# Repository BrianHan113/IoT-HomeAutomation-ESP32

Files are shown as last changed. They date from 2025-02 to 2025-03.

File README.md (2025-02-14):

# IoT-HomeAutomation-ESP32

IoT Home Automation system using ESP32s to control various peripherals, developed with amazing help and under supervision of Alex Risos from Risos Enterprises for my summer 2024-25 internship. This project comes with pre-made examples of peripherals, but the esp32-Receiver-Firmware can be flashed and easily modified on any ESP32 for any custom functionality. There are 2 versions of the project, read the Known Issues section to see why.

<table align="center">
  <tr>
    <th style="text-align:center;">Simplified (Recommended)</th>
    <th style="text-align:center;">Full</th>
  </tr>
  <tr>
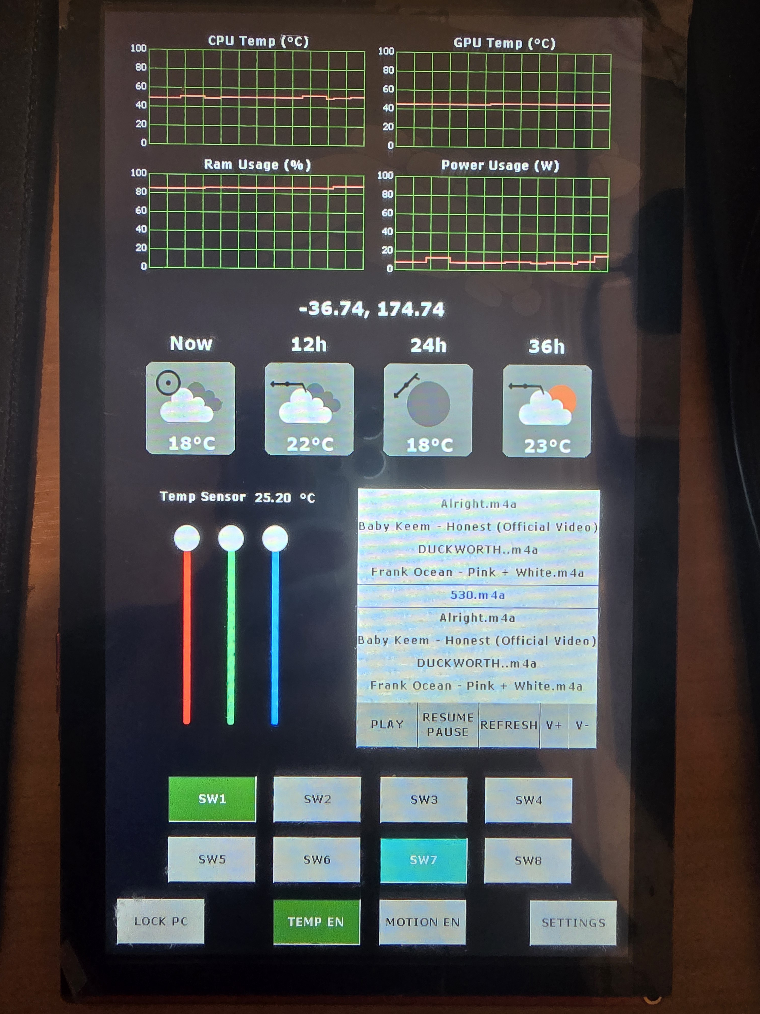
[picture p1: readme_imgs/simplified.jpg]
    <td align="center"></td>
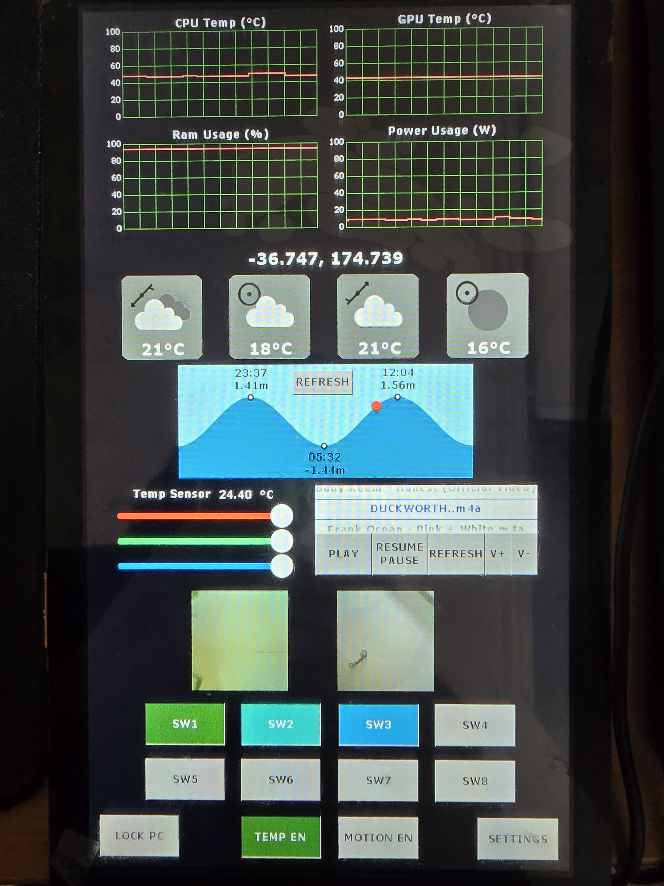
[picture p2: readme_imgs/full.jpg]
    <td align="center"></td>
  </tr>
</table>

## Demo Video (Simplified Version)

<a href="https://www.youtube.com/watch?v=xSinmTBI6Ek" target="_blank" rel="noopener noreferrer">
    
</a>

This demo covers the linking and usage of the esp32-SSR, esp32-Status-LED, esp32-Motion-Sensor, and esp32-Temp-Sensor. I linked them all onto one switch for demonstration purposes, but you could obviously link them to other switches. The SSR isn't hooked up to anything, but it is rated for any 100-240VAC load. With just this bare bones setup, you could automate many things, like setting off an emergency alarm when the temperature sensor triggers, turning on a light bulb when entering a room, etc. 

## Summary of features
* Detection and pairing with powered ESPs that have the receiver firmware programmed
* Link any paired ESP to any of 8 switches on nextion display, can link multiple ESPs on one switch
* Control of 2-channel low-level solid state relays
* Quadruple state switches with actions of A, B, A+B or OFF
* Control of LED strips (Status-LED which shows a colour dependant on Gpu Temperature, and LED-Strip for colour picking using RGB sliders on nextion GUI)
* Trigger switches using a Motion Sensor
* Trigger switches using a Temperature Sensor
* Trigger switches and/or enable sensors with a scheduler
* 2 Camera slots for image captures (Not in simplified version)
* Weather information with adjustable time range
* Tide extremes and current tide height information (Not in simplified version)
* CPU Temperature, GPU Temperature, Ram Usage and Power consumption shown on nextion display as waveforms
* Music player
* Lock PC button

## How to Use
### Getting started
1. Flash esp32-HW-monitor on central esp32-s3
2. Flash as many receiver esps as you would like
3. Connect COM port of esp32-s3 to a USB port on your computer (See wiring diagram)
4. Flash whichever .HMI file (simplified or full) in nextion-HMI onto the nextion 
5. Make sure the esp32-s3 and the nextion share a common ground
6. Start the ArduinoWeatherHardwareMonitor desktop app, make sure to run as admin. For quick setup with no TideAPI functionality, execute ArduinoWeatherHardwaremonitor_RELEASE/SerialSender.exe. If you want Tide functionality, you must add your API key to the Secret_PLACEHOLDER.cs file, and recompile the project in Visual Studio.
7. Select the appropriate serial port by right clicking the tray icon

At this point, the waveforms and weather information should have loaded on the main page, the LOCKPC button and the music player should be working. Right click the tray icon to select your WinAmp installation folder and your music folder. You will only have to do this once, unless you change your WinAmp path or your music folder. The music player plays MP3, MIDI, MOD, MPEG-1, AAC, M4A, FLAC, WAV, WMA, Ogg Vorbis.

### General Information
I have included all the specific hardware/sensors/parts I used for all the different peripherals under Wiring Diagrams. You can definitely use different hardware, but you will likely have to modify some code in the peripheral projects.

All peripheral projects have EspIDs in their main.cpp files. You can change the names of these to anything you want. E.g. "living room lights", "garage motion sensor", etc.

In settings, you can click directly on any numbers to bring up a on-screen numerical keyboard, and press the <strong>X</strong> to clear selections. You should always hit <strong>APPLY</strong> after changing any settings to keep the system up to date and accurate to what is shown on the settings page.

### Linking and Turning Peripherals on/off

Can be used for esp32 or esp8266, just flash the appropriate receiver firmware.

<table align="center">
  <tr>
    <td><div>
    <ol>
      <li>Press <strong>SETTINGS</strong>, then <strong>SCANESPS</strong> in the top left. Wait a couple of seconds for the peripherals to connect.</li>
      <li>Link a switch to any peripheral and hit <strong>APPLY</strong> on the bottom left.</li>
      <li>Exit back to the main page. You should now be able to turn that peripheral on/off using the switch you selected.</li>
    </ol>
    <p>Each switch has 4 states which go in sequence of ONA, ONAB, ONB, OFF. This allows each peripheral to handle 2 different actions, A and B, where ONAB is turning on both at the same time. This synergizes with usage of 2 channel SSRs, as seen in esp32-SSR. </p> <p>For the standard esp32/esp8266-Receiver-Firmware, all three ON states will just turn the builtin LED on, but this can be easily modified.</p>
  </div></td>
    <td align="center"><div style="align-items: center;">
  <div>
    <div>
      <h4>Linking Switches</h4>
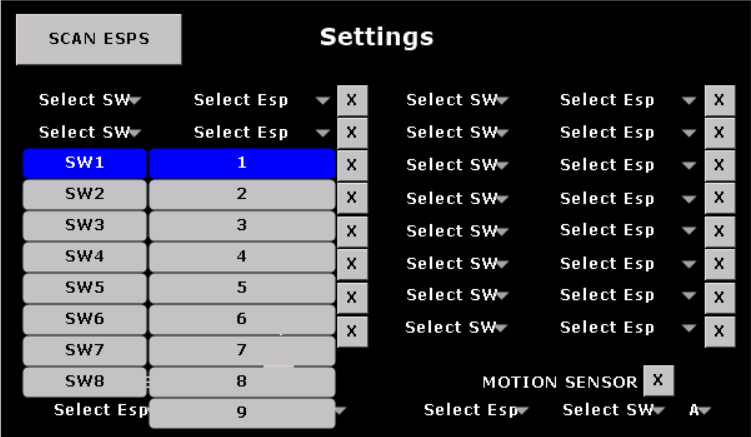
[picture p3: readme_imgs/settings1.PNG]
      
    </div>
    <div>
      <h4>4 Switch States in order</h4>
      
    </div>
  </div>
</div></td>
  </tr>
</table>

### Solid State Relays
Link to a switch in settings, and press the switch on the main screen to turn on whatever channel(s) you want. 

### Temperature Sensor

<table align="center">
  <tr>
    <td><div>
    <ol>
      <li><strong>Select ESP</strong>: The device that is connected to the temperature sensor</li>
      <li><strong>Select SW</strong>: The Switch that should be triggered when the temperature exceeds the trigger temperature</li>
      <li><strong>Channel selection</strong>: Which channel of the switch should be turned on (A, B, AB)</li>
      <li><strong>Trigger SW at</strong>: The temperature threshold, in celcius, where anything that exceeds it will trigger the connected switch</li>
      <li><strong>Hysterisis</strong>: What percentage of the trigger temperature does the measured temperature need to fall below in order to turn the switch off. E.g., if trigger temp is 50C, and hystersis is 50%, when triggered, the measured temperature must fall below 25C in order for the switch to turn off automatically.</li>
    </ol>
    <p>After selecting these settings, you must hit <strong>APPLY</strong> and navigate back to the main screen, and press <strong>TEMP EN</strong> to enable the sensor to make automatic changes. If it any point you wish to override the sensor/ignore it, just press <strong>TEMP EN</strong> again to disable it.</p>
  </div></td>
    <td align="center"><div style="align-items: center;">
  <div>
    <div>
      <h4>Temperature Sensor</h4>
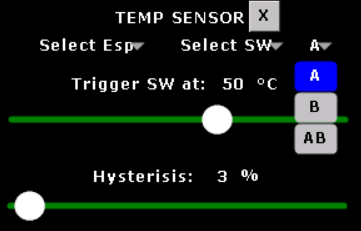
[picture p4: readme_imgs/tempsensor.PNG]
      
    </div>
  </div>
</div></td>
  </tr>
</table>

### Motion Sensor

<table align="center">
  <tr>
    <td><div>
    <ol>
      <li><strong>Select ESP</strong>: The device that is connected to the motion sensor</li>
      <li><strong>Select SW</strong>: The Switch that should be triggered when motion is detected</li>
      <li><strong>Channel selection</strong>: Which channel of the switch should be turned on (A, B, AB)</li>
      <li><strong>Timeout</strong>: How long the switch stays on after motion is detected, before turning off. 0 minutes will default to 1 second.</li>
    </ol>
    <p>After selecting these settings, you must hit <strong>APPLY</strong> and navigate back to the main screen, and press <strong>MOTION EN</strong> to enable the sensor to make automatic changes. If it any point you wish to override the sensor/ignore it, just press <strong>MOTION EN</strong> again to disable it.</p>
  </div></td>
    <td align="center"><div style="align-items: center;">
  <div>
    <div>
      <h4>Motion Sensor</h4>
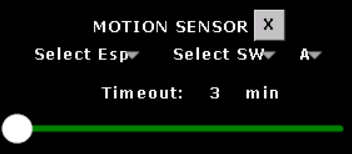
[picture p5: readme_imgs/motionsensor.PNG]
      
    </div>
  </div>
</div></td>
  </tr>
</table>

### Scheduler
Make sure the desktop app is open, and the serial port to the central esp is connected.

<table align="center">
  <tr>
    <td><div>
    <ol>
      <li><strong>Select SW</strong>: The Switch that should be turned on at Start time, and off at End time</li>
      <li><strong>Channel selection</strong>: Which channel of the switch should be turned on/off (A, B, AB)</li>
      <li><strong>Start</strong>: Turn selected switch on at this time</li>
      <li><strong>End</strong>: Turn selected switch off at this time</li>
      <li><strong>X</strong>: Will unschedule the switch</li>
    </ol>
    <p>For the temperature and motion sensors, the scheduler will turn the <strong>TEMP EN</strong> and <strong>MOTION EN</strong> on/off instead. For this case, the channel selection is not needed, and hence is ignored.</p>
  </div></td>
    <td align="center"><div style="align-items: center;">
  <div>
    <div>
      <h4>Scheduler</h4>
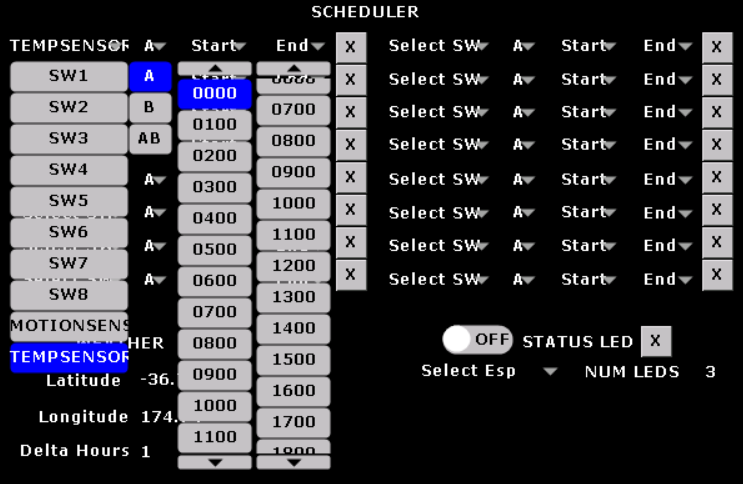
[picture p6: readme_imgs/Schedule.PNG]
      
    </div>
  </div>
</div></td>
  </tr>
</table>

### LED Strip

<table align="center">
  <tr>
    <td><div>
    <ol>
      <li><strong>Select ESP</strong>: The device that is connected to the LED Strip</li>
      <li><strong>NUM LEDS</strong>: How many LEDs to show.</li>
      <li><strong>Link</strong>: You must then link the LED Strip device to a switch in order to turn it on.</li>
      <li><strong>Colour</strong>: Change the colour of the LED Strip using the 3 RGB sliders on the main screen.</li>
    </ol>
  </div></td>
    <td align="center"><div style="align-items: center;">
  <div>
    <div>
      <h4>LED Strip</h4>
      
    </div>
    <div>
      <h4>Link LED Strip</h4>
      
    </div>
  </div>
</div></td>
  </tr>
</table>

### Status LED Strip

<table align="center">
  <tr>
    <td><div>
    <ol>
      <li><strong>Select ESP</strong>: The device that is connected to the LED Strip</li>
      <li><strong>NUM LEDS</strong>: How many LEDs to show.</li>
      <li><strong>Turn On</strong>: Apply the settings first, then turn the strip on and off using the switch.</li>
      <li><strong>Brightness</strong>: Use the slider to change the brightness of the LED strip.</li>
    </ol>
    <p>Currently, the status LED strip just reports the GPU temperature scaled from 30 to 100 degrees celcius to the CHSV colour scale, where 100C is red, and 30C is aqua, with everything else in between. You can modify this in the sendTempData task in HW-monitor, and the receiver_espnow in Status-LED to add whatever else you want it to report.</p>
    <p>Also note that the ON/OFF switch and the brightness slider do not require hitting <strong>APPLY</strong> to take action.</p>
  </div></td>
    <td align="center"><div style="align-items: center;">
  <div>
    <div>
      <h4>Status LED Strip</h4>
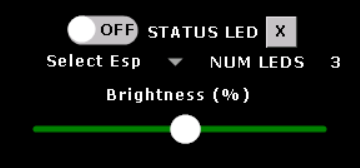
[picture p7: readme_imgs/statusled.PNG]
      
    </div>
</div></td>
  </tr>
</table>

### Weather Settings
<table align="center">
  <tr>
    <td><div>
    <ol>
      <li><strong>Lat & Long</strong>: Standard Lat Long, + for North of equator, + for East of Prime Meridian</li>
      <li><strong>Delta Hours</strong>: Time gap between each weather forecast. E.g. delta hour of 6 will give a forecast of now, +6h, +12h, +18h in the main screen.</li>
      <li>Hit <strong>APPLY</strong>, It will take a couple seconds for the weather icons to be updated.</li> 
    </ol>
    <p>Note that the weather is automatically updated every 5 minutes. Pressing <strong>APPLY</strong> manually fetches new data.</p>
  </div></td>
    <td align="center"><div style="align-items: center;">
  <div>
    <div>
      <h4>Weather Settings</h4>
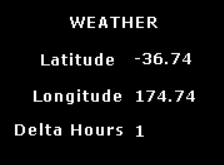
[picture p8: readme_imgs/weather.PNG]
      
    </div>
  </div>
</div></td>
  </tr>
</table>

## Wiring Diagrams

### Nextion and Central ESP
* Nextion - NX1060P101-011C-I, RX of Nextion to pin 17, TX of Nextion to pin 18
* ESP32-S3 - Connect USB Port on the ESP to the PC
* SD Card in Nextion if using ESP-CAMs, otherwise not necessary
* Make sure ESP shares common ground with Nextion and the PSU
<div>
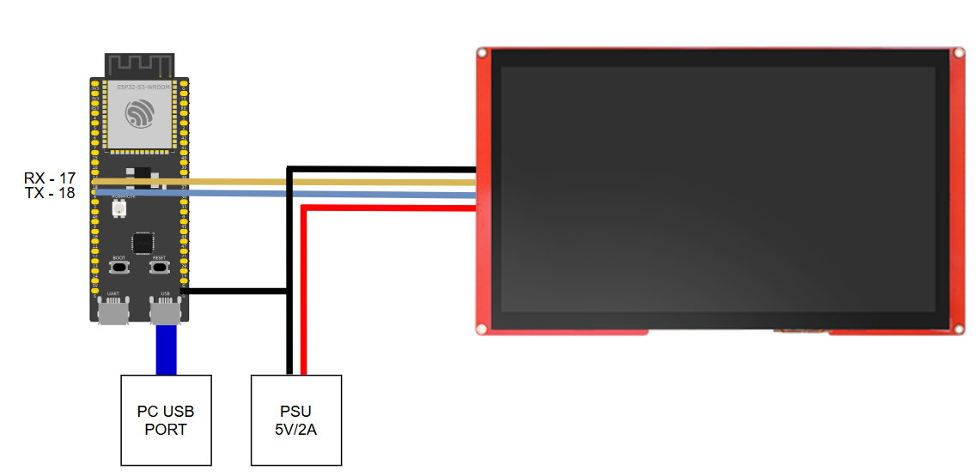
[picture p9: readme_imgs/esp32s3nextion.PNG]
  
</div>

### Temperature Sensor
* ESP32 - data line from sensor connected to GPIO pin 26.
* DHT22 - 3.3V VCC
* 1 KOhm Resistor - Make sure to add a pull-up resistor between data and VCC for stable transmission (see official DHT22 documentation).
<div>
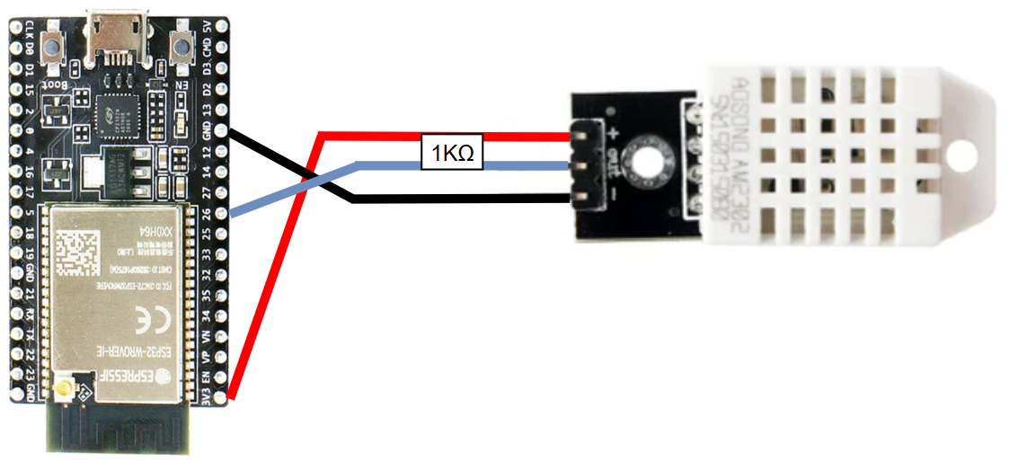
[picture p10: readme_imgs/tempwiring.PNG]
  
</div>

### Motion Sensor
* ESP32 - Data line on PIR sensor to pin 13
* PIR Sensor - HC-SR501, 5V VCC
<div>
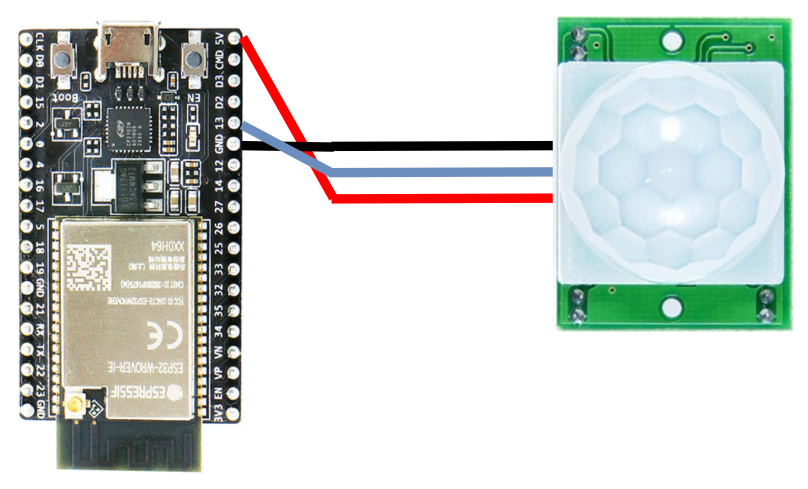
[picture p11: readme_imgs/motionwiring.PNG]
  
</div>

### LED Strip & Status LED Strip
* ESP32 - Primary data line of LED Strip connected to pin 26
* LED Strip - WS2815 12V LED Strip 
* I have 19 LEDs on my LED strip, but you should change that definition to however many LEDs you have in the main file of the esp32-LED-strip project.
<div>
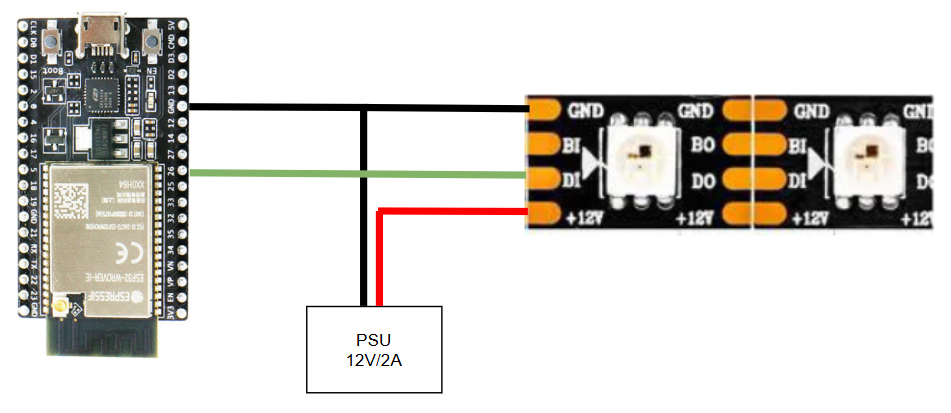
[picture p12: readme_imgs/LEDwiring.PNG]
  
</div>

### Solid State Relays
* ESP32
* SSR - G3MB-202P 2-channel low-level, 5V DC input, 240VAC 2A output
* Channels 1 and 2 are controlled by esp32 pins 27 and 26 respectively. 
<div>
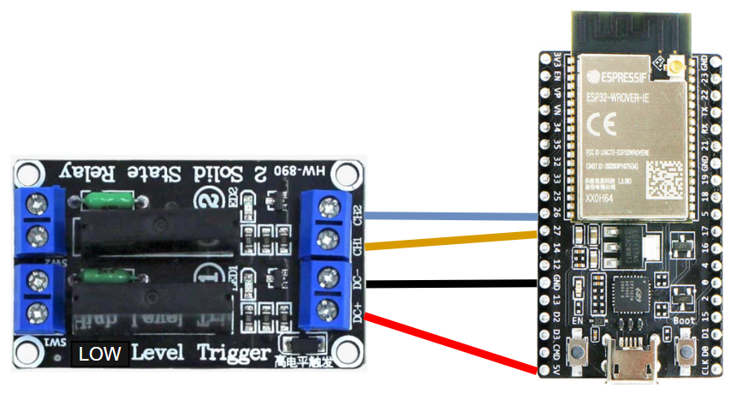
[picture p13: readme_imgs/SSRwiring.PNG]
  
</div>

## Known Issues
* Camera capture is very slow, around 10-15 seconds just for a single still image, and during this all buttons are unresponsive. It "works", but is generally pretty unusable, and hence has been disabled. It can easily be enabled by uncommenting code in the setup() function in the main file of HW-Monitor and filling in secret files in the HW-Monitor and CAM projects for WiFi SSID and Password.
* Tide data is also excluded in the simplified version, as the API used for the data (Stormglass.io) is unstable and could likely get rid of their free tier pricing. If stormglass is still free when reading this, or you have a paid api key, you can simply uncomment the task in the setup() function in the main file of HW-Monitor where the tasks are created, and provide your api key in the secret file in the ArduinoHardwareWeatherMonitor C# app.
* Make sure to select the serial port in the desktop app first, and then configure any settings with the receiver ESPs. Doing it the other way causes problems with the central ESP's memory and will result in unstable behaviour.

## Thank You
Alex Risos for supervising this project and always providing amazing guidance, help, and feedback. Definitely would not have been able to complete this project without his help.

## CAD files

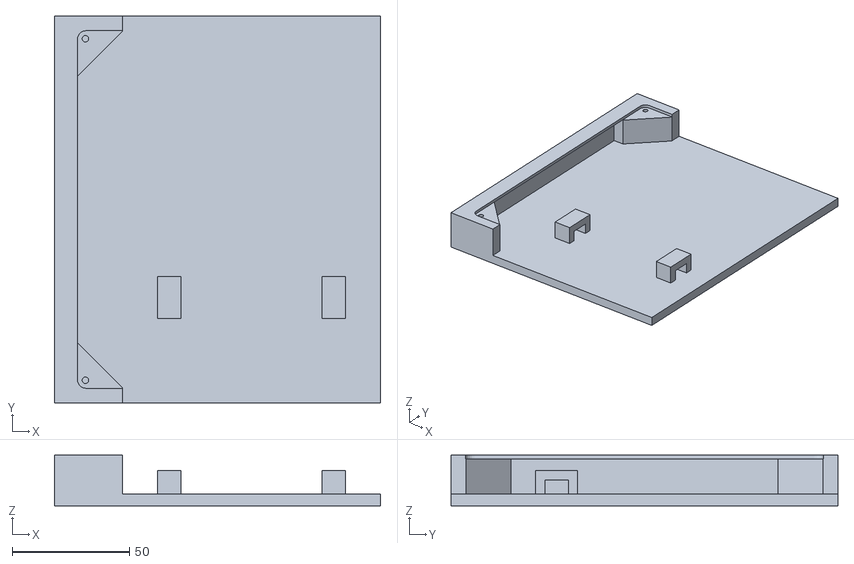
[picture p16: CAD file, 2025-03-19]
CAD-assets/nextion_mount_simplehalf.stl
139.0 x 165.0 x 21.6

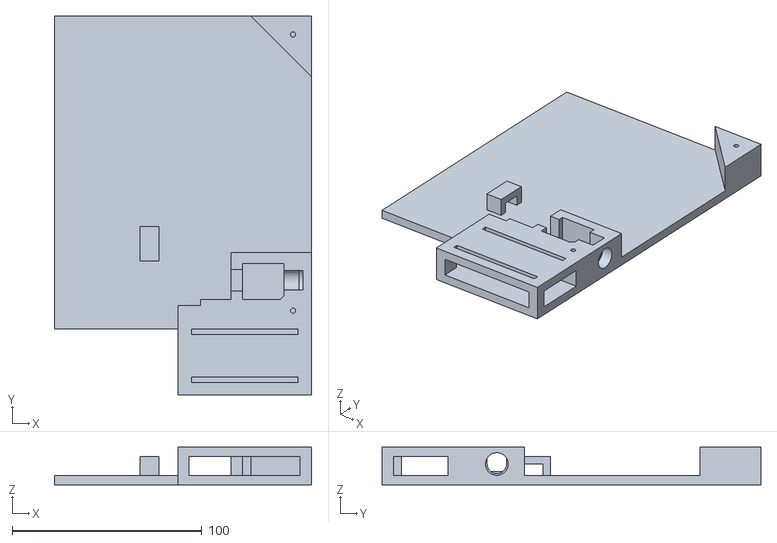
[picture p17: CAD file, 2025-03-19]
CAD-assets/nextion_mount_compelxhalf.stl
135.5 x 199.7 x 20.0

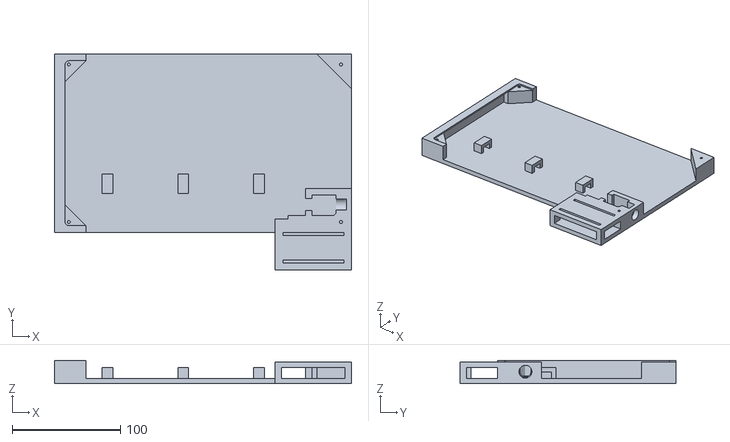
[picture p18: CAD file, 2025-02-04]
CAD-assets/Body4.stl
274.5 x 199.7 x 21.6

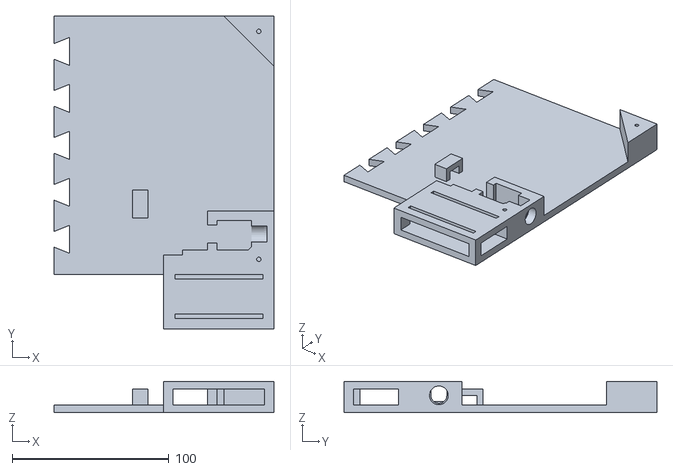
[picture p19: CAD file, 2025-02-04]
CAD-assets/espHalf.stl
140.5 x 199.7 x 20.0

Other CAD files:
CAD-assets/waireHalf.stl
CAD-assets/camera-case.f3z

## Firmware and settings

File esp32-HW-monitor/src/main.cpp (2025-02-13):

// Copyright (c) 2025 RisosEnterprises Ltd. All rights reserved.
// Developed by RisosEnterprises Ltd, Auckland, New Zealand.
// Licensed under Creative Commons Attribution-NonCommercial 4.0 International (CC BY-NC 4.0).
// See https://creativecommons.org/licenses/by-nc/4.0/ for details.
// Author: Brian Han

// USING ESP32-S3 with COM and USB port
// Because we set ARDUINO_USB_CDC_ON_BOOT=1 in setup,
// Serial0 is our extra Serial, and Serial is our normal Serial
// Serial0 -> COM Port
// Serial  -> USB Port
// Usage: Send & receive data at COM port, use USB port as normal for debugging

#include "tasks.h"
#include "espnow_manager.h"
#include "secrets.h"
#include "WiFi.h"
#include "addresses_helper.h"
#include "esp_wifi.h"
#include "security_camera.h"

HardwareSerial nextion(2);

SemaphoreHandle_t hardwareDataSemaphore;
SemaphoreHandle_t weatherBinSemaphore;
SemaphoreHandle_t tideBinSemaphore;
QueueHandle_t commandQueue;
QueueHandle_t sendNextionQueue;
const uint8_t COMMAND_QUEUE_LEN = 10;
const uint8_t SEND_NEXTION_QUEUE_LEN = 50;

// All task handles
TaskHandle_t receiveHardwareDataHandle = NULL;
TaskHandle_t sendNextionSerialHandle = NULL;
TaskHandle_t sendHardwareDataHandle = NULL;
TaskHandle_t sendWeatherDataHandle = NULL;
TaskHandle_t sendTideDataHandle = NULL;
TaskHandle_t receiveNextionSerialHandle = NULL;
TaskHandle_t executeCommandsHandle = NULL;
TaskHandle_t sendTempDataHandle = NULL;

void setup()
{
  Serial0.begin(115200);
  Serial.begin(115200);
  nextion.begin(115200, SERIAL_8N1, 18, 17); // RX, TX

  delay(3000);

  WiFi.mode(WIFI_STA);
  WiFi.disconnect();
  esp_wifi_set_channel(1, WIFI_SECOND_CHAN_NONE);

  // Setup for camera capture functionality - see README
  // WiFi.mode(WIFI_AP_STA);
  // WiFi.begin(WIFI_SSID, WIFI_PASS);

  // // Wait for WiFi connection
  // int tries = 0;
  // while (WiFi.status() != WL_CONNECTED && tries < 10)
  // {
  //   delay(500);
  //   Serial.println("Connecting to WiFi...");
  //   tries++;
  // }

  // if (!SPIFFS.begin(true))
  // {
  //   Serial.println("SPIFFS initialization failed!");
  //   return;
  // }

  if (esp_now_init() != ESP_OK)
  {
    Serial.println("ESP-NOW init failed");
    return;
  }
  Serial.println("Initialized ESP-NOW");

  esp_now_register_recv_cb(OnDataRecv);
  espNowAddReceiver(broadcastAddress);

  hardwareDataSemaphore = xSemaphoreCreateCounting(2, 0); // 2 slots for sendHardwareData and sendTempData
  weatherBinSemaphore = xSemaphoreCreateBinary();
  tideBinSemaphore = xSemaphoreCreateBinary();
  commandQueue = xQueueCreate(COMMAND_QUEUE_LEN, sizeof(char[500]));
  sendNextionQueue = xQueueCreate(SEND_NEXTION_QUEUE_LEN, sizeof(char[100]));

  xTaskCreatePinnedToCore(receiveHardwareData, "Recieve Hardware Data from c# app", 16384, NULL, 2, &receiveHardwareDataHandle, PRO_CPU_NUM);
  xTaskCreatePinnedToCore(sendNextionSerial, "Send commands to nextion", 16384, NULL, 1, &sendNextionSerialHandle, APP_CPU_NUM);
  xTaskCreatePinnedToCore(sendHardwareData, "Send Hardware Data to nextion", 16384, NULL, 1, &sendHardwareDataHandle, APP_CPU_NUM);
  xTaskCreatePinnedToCore(sendWeatherData, "Send Weather Data to nextion", 16384, NULL, 1, &sendWeatherDataHandle, APP_CPU_NUM);
  // Uncomment to enable tide data transfer - see README
  // xTaskCreatePinnedToCore(sendTideData, "Send Tide Data to nextion", 16384, NULL, 1, NULL, APP_CPU_NUM);
  xTaskCreatePinnedToCore(receiveNextionSerial, "Receive data from nextion", 16384, NULL, 2, &receiveNextionSerialHandle, APP_CPU_NUM);
  xTaskCreatePinnedToCore(executeCommands, "Execute nextion commands", 16384, NULL, 2, &executeCommandsHandle, APP_CPU_NUM);
  xTaskCreatePinnedToCore(sendTempData, "Send Hardware temperature data", 2048, NULL, 1, &sendTempDataHandle, APP_CPU_NUM);
  vTaskSuspend(sendTempDataHandle);

  Serial.print("Reset reason: ");
  Serial.println(esp_reset_reason());

  vTaskDelete(NULL); // Delete the main task -> loop() will never run
}

void loop()
{
  Serial.println("------------Memory Metrics------------");
  Serial.println("Free Heap: " + String(ESP.getFreeHeap()));
  UBaseType_t stackLeft = uxTaskGetStackHighWaterMark(NULL);
  Serial.println("Main stack: " + String(stackLeft));
  stackLeft = uxTaskGetStackHighWaterMark(receiveHardwareDataHandle);
  Serial.println("receiveHardwareData stack: " + String(stackLeft));
  stackLeft = uxTaskGetStackHighWaterMark(sendNextionSerialHandle);
  Serial.println("sendNextionSerial stack: " + String(stackLeft));
  stackLeft = uxTaskGetStackHighWaterMark(sendHardwareDataHandle);
  Serial.println("ssendHardwareData stack: " + String(stackLeft));
  stackLeft = uxTaskGetStackHighWaterMark(sendWeatherDataHandle);
  Serial.println("sendWeatherData stack: " + String(stackLeft));
  stackLeft = uxTaskGetStackHighWaterMark(receiveNextionSerialHandle);
  Serial.println("receiveNextionSerial stack: " + String(stackLeft));
  stackLeft = uxTaskGetStackHighWaterMark(executeCommandsHandle);
  Serial.println("executeCommands stack: " + String(stackLeft));
  stackLeft = uxTaskGetStackHighWaterMark(sendTempDataHandle);
  Serial.println("sendTempData stack: " + String(stackLeft));
  Serial.println("--------------------------------------");

  vTaskDelay(2000 / portTICK_PERIOD_MS);
}

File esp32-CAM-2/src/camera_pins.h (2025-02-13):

// Copyright 2015-2016 Espressif Systems (Shanghai) PTE LTD
//
// Licensed under the Apache License, Version 2.0 (the "License");
// you may not use this file except in compliance with the License.
// You may obtain a copy of the License at
//
//     http://www.apache.org/licenses/LICENSE-2.0
//
// Unless required by applicable law or agreed to in writing, software
// distributed under the License is distributed on an "AS IS" BASIS,
// WITHOUT WARRANTIES OR CONDITIONS OF ANY KIND, either express or implied.
// See the License for the specific language governing permissions and
// limitations under the License.
//
// Modified by RisosEnterprises Ltd. 2025

#if defined(CAMERA_MODEL_AI_THINKER)
#define PWDN_GPIO_NUM 32
#define RESET_GPIO_NUM -1
#define XCLK_GPIO_NUM 0
#define SIOD_GPIO_NUM 26
#define SIOC_GPIO_NUM 27

#define Y9_GPIO_NUM 35
#define Y8_GPIO_NUM 34
#define Y7_GPIO_NUM 39
#define Y6_GPIO_NUM 36
#define Y5_GPIO_NUM 21
#define Y4_GPIO_NUM 19
#define Y3_GPIO_NUM 18
#define Y2_GPIO_NUM 5
#define VSYNC_GPIO_NUM 25
#define HREF_GPIO_NUM 23
#define PCLK_GPIO_NUM 22

// 4 for flash led or 33 for normal led
#define LED_GPIO_NUM 4

#else
#error "Camera model not selected"
#endif

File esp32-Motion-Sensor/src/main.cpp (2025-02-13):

// Copyright (c) 2025 RisosEnterprises Ltd. All rights reserved.
// Developed by RisosEnterprises Ltd, Auckland, New Zealand.
// Licensed under Creative Commons Attribution-NonCommercial 4.0 International (CC BY-NC 4.0).
// See https://creativecommons.org/licenses/by-nc/4.0/ for details.
// Author: Brian Han

#include <Arduino.h>
#include <receiver_espnow.h>

#define LED 2
#define PIR_PIN 13

String EspID = "MOTION_SENSOR";
uint8_t senderMac[6];

bool isEnabled = false;

// Configs based on settings on nextion
String linkedSwitch = "";
int timeoutMins = -1;
String channel = "";

boolean pirState;
boolean motionDetected = false;
TimerHandle_t turnOffTimer = NULL;

void turnSwitchOff(TimerHandle_t xTimer)
{
  if (!isEnabled)
  {
    Serial.println("Tried to turn off but Motion Sensor not enabled");
    motionDetected = false;
    return;
  }

  char dataToSend[32] = "";
  Serial.println("Function executed after delay.");
  strcpy(dataToSend, (linkedSwitch + "OFF").c_str());
  motionDetected = true;

  esp_err_t result = esp_now_send(senderMac, (uint8_t *)dataToSend, sizeof(dataToSend));

  if (result == ESP_OK)
  {
    Serial.println("Sending Motion info confirmed");
  }
  else
  {
    Serial.printf("Sending Motion info error: %d\n", result);
  }
  motionDetected = false;
}

void motionDetectTask(void *params)
{
  while (true)
  {
    bool isConfigured = false;
    if (linkedSwitch != "" && timeoutMins != -1 && channel != "")
    {
      isConfigured = true;
    }

    if (!isConfigured)
    {
      Serial.println("Motion Sensor not configured. Waiting...");
      vTaskDelay(1000 / portTICK_PERIOD_MS); // Yield for watchdog reset
      continue;
    }

    if (!isEnabled)
    {
      Serial.println("Motion Sensor not enabled");
      vTaskDelay(1000 / portTICK_PERIOD_MS); // Yield for watchdog reset
      continue;
    }

    char dataToSend[32] = "";
    pirState = digitalRead(PIR_PIN);

    if (!motionDetected && pirState)
    {
      strcpy(dataToSend, (linkedSwitch + "ON" + channel).c_str());
      motionDetected = true;

      esp_err_t result = esp_now_send(senderMac, (uint8_t *)dataToSend, sizeof(dataToSend));

      if (result == ESP_OK)
      {
        Serial.println("Sending Motion info confirmed");
      }
      else
      {
        Serial.printf("Sending Motion info error: %d\n", result);
      }
      vTaskDelay(1000 / portTICK_PERIOD_MS);
      // Create and start FreeRTOS timer
      int timeoutInTicks = timeoutMins * 60 * 1000 / portTICK_PERIOD_MS; // Timeout in ticks

      if (timeoutInTicks <= 0)
      {
        timeoutInTicks = 1000 / portTICK_PERIOD_MS;
      }

      turnOffTimer = xTimerCreate(
          "MyTimer",
          pdMS_TO_TICKS(timeoutInTicks),
          pdFALSE,
          (void *)0,
          turnSwitchOff);

      xTimerStart(turnOffTimer, 0);

      vTaskDelay(1000 / portTICK_PERIOD_MS);
    }

    vTaskDelay(100 / portTICK_PERIOD_MS); // Ensure task is yielding to prevent watchdog trigger
  }
}

void setup()
{
  pinMode(LED, OUTPUT);
  pinMode(PIR_PIN, INPUT);
  Serial.begin(115200);
  WiFi.mode(WIFI_STA);
  WiFi.disconnect();
  esp_wifi_set_channel(1, WIFI_SECOND_CHAN_NONE);
  esp_now_init();

  esp_now_register_send_cb(OnDataSent);
  esp_now_register_recv_cb(OnDataRecv);

  // Create FreeRTOS timer
  turnOffTimer = xTimerCreate("turnOffTimer", pdMS_TO_TICKS(1), pdFALSE, (void *)0, turnSwitchOff);

  // Create and start motion detection task
  xTaskCreatePinnedToCore(motionDetectTask, "Motion detection", 8192, NULL, 1, NULL, APP_CPU_NUM);

  vTaskDelete(NULL); // Delete main task as it is not used
}

void loop()
{
}

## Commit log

2025-02-02 Init commit
    [camera-case.f3z]
2025-02-04 Update CAD models and provide stl files
    [Body4.stl, espHalf.stl, waireHalf.stl]
2025-02-06 Fix bug of nextion serial overflow by introducing delays in nextion code, and increase stack sizes for tasks
    [main.cpp, tasks.cpp]
2025-02-06 Reduce delays when applying settings, fix for motion sensor timeout, reduce delay for winamp setup
    [main.cpp, receiver_espnow.cpp, tasks.cpp]
2025-02-08 Fix for central esp, keep on the same wifi channel as peripherals
    [main.cpp]
2025-02-08 Modify how hysterisis 0 works for temp sensor
2025-02-08 Changed how motion sensor enable/disable works, made it more intuitive
2025-02-10 Fix nextion visual bug known issue by making a centralised queue to send nextion commands
    [espnow_manager.cpp, main.cpp, security_camera.cpp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]
2025-02-10 Fix out of bounds for LED strips
    [main.cpp]
2025-02-12 Add brightness slider for status LED strip
2025-02-12 Add debugging logs to check for memory leaks, none detected
    [main.cpp]
2025-02-13 Switch SSR channel pins to make wiring better
2025-02-13 Add wiring diagrams to readme, and release compiled c# app
2025-03-19 CAD files
    [nextion_mount_compelxhalf.stl, nextion_mount_simplehalf.stl]
2025-04-14 Remove second serial port due to compatability issues on some PCs
    [tasks.cpp]
2025-04-14 Fix thread starvation issue
2025-04-15 Atomic timer guard
2025-04-16 Fixed thread starvation issue
2025-04-16 Improve gpu power stat
